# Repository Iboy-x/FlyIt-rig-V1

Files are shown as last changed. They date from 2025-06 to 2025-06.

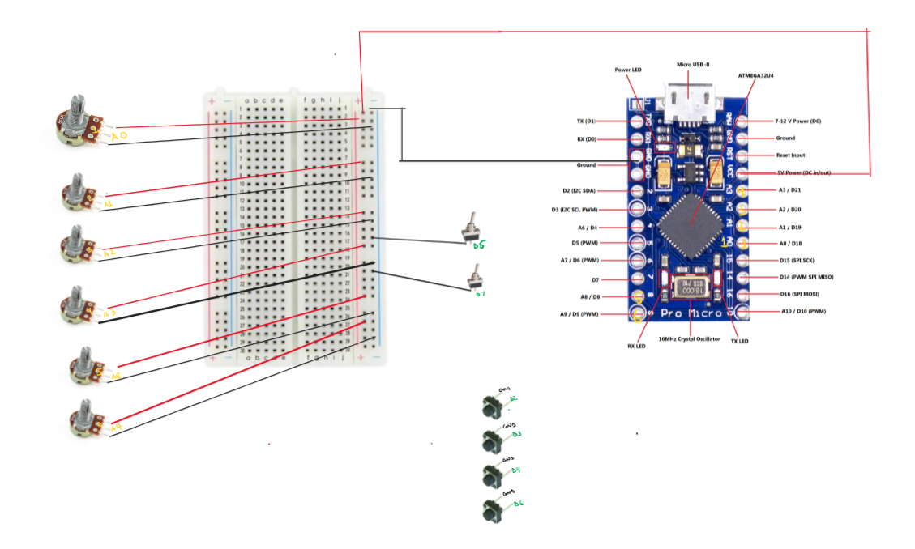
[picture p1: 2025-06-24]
Images/schematic.png

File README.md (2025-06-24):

# 🛫 FlyIt Rig V1
FlyIt Logo

**FlyIt Rig V1** is a DIY, USB-compatible flight yoke + throttle + pedal brake system made for **Microsoft Flight Simulator 2025**. The goal is to build a complete, realistic flight control rig — using affordable parts, Arduino, custom 3D prints, and pure ✨ sweat + logic ✨.

## 🎯 Project Goal

> Build a budget-friendly, USB-compatible flight controller that works with MSFS 2025 — including:
- A smooth, precise **flight yoke**
- Functional **throttle quadrant**
- Responsive **pedal brake system**
- Custom **control panel** with switches/buttons

I found lots of amazing YouTube builds — but only for individual components. My mission? **Combine them all into one fully working beast.**

---

## 🧠 Why It’s Advanced

- Heavy use of **CAD** & **3D printing** for mechanical parts
- Precision design — bearings, rods, and mounts need to be aligned just right
- **Arduino HID programming** to make it work as a real USB joystick
- Reverse engineering to get it working seamlessly with **Microsoft Flight Simulator**
- Tons of debugging, prototyping, and integration

This ain't your average DIY — it’s serious hacker engineering 😤

---

## 🛠️ Tech Stack

- 🧠 **Arduino Micro** (native USB HID support)
- 💻 Microsoft Flight Simulator 2025
- 🧰 Fusion 360 (CAD + 3D printing)
- 🛞 Bearings, steel rods, potentiometers
- 🧼 Custom control box with buttons/switches

---

## 🗂️ Build Plan

I’ll be building in stages — one module at a time:

1. **Flight Yoke** (axis + spring + centering system)
2. **Throttle Quadrant** (with friction + detents)
3. **Control Panel** (switches, buttons, and toggle controls)
4. **Brake Pedals** (paddle-style system)

Every step will be logged in `JOURNAL.md` for transparency and learning.

---

## 🔗 Inspirations

- [DIY Throttle Quadrant Guide](https://youtu.be/BRk2fzmqIq4)
- [Pedal Brake System Concept](https://youtu.be/YEzn16pNJ3I)

More design references and files will be added as I build & iterate.

---

## 🚧 Current Status

> ✅ Proposal submitted on Pitstop  
> 🚧 Hardware sourcing ongoing  
> 🔜 CAD design for yoke and controller done
> 🔜 First prototype in progress

---

## 📸 Images & Progress



Yoke Render Desing: 



Controller Render: 



Pedal Render:



### Schemtics 



---

## 🧾 License

MIT — feel free to remix and build your own FlyIt Rig! Just don’t forget to share it back with the community 💛

---
## 💸 Bill of Materials (Est. $150)

| Component | Qty | Est. Price |
|---|-----|---|
| Arduino Micro | 1 | $15 |
| 8mm x 200mm Steel Rods | 8 | $50 |
| 30x42x7 Bearings | 6 | $25 |
| LM8UU Linear Bearings 8mm*45mm| pack of 10 | $5.5 |
| V-Slot Bearings | 1pack of 12 | $9 |
| 3/8 x 7/8 Bearings | 2 | $3 |
| Potentiometers | 8 | $5 |
| Switches & Buttons | Few | ~$10 |
| 6mm Mounting Hubs | 2 | $12 |
| Wiring, base, misc parts | - | ~$15 |
|Almunimum angle rods 200mm | 2 | $20 |
| **3D Printing** | - | Covered by Hack Club (#printing-legion) |

---

### ✈️ Wheels up, dreams up.
> Made by [@AbdulMoiz](https://github.com/iboy-x) · Hack Clubber · Pilot in progress · Builder for life

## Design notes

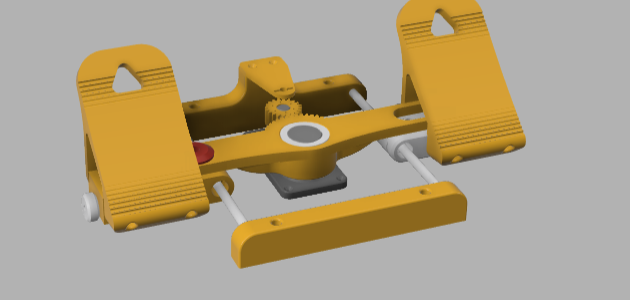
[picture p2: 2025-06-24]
Images/padel1.png

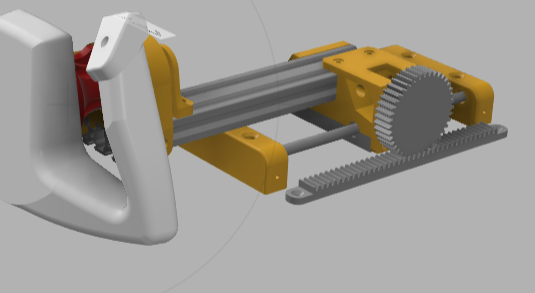
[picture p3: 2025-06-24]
Images/yoke2.png

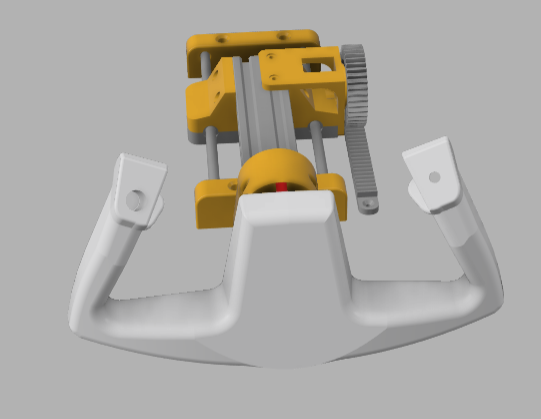
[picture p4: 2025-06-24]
Images/YOke1.png

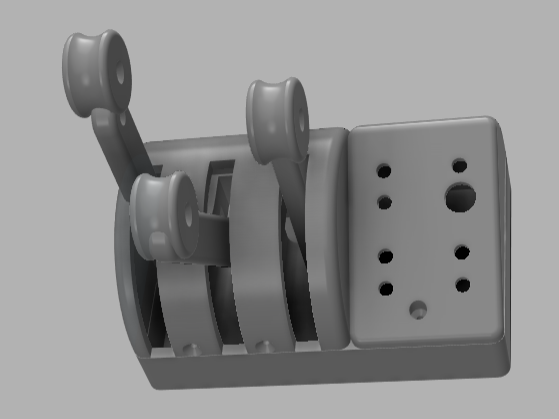
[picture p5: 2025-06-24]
Images/Controller.png

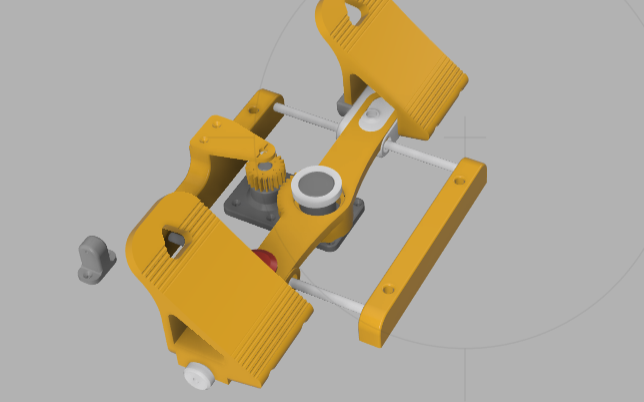
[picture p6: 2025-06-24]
Images/padel2.png

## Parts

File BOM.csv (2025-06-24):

Part Name | Quantity | Estimated Cost (USD) | Supplier | Link | Notes
Arduino Micro | 1 | 10 | AliExpress | https://www.aliexpress.com/item/1005006160273196.html | Built-in USB HID
8mm x 200mm Steel Rods | 8 | 40 | AliExpress | https://www.aliexpress.com/item/1005001380920260.html | Yoke + linear motion axis
30x42x7 Bearings | 6 | 20 | AliExpress | https://www.aliexpress.com/item/1005007420073930.html | Bearing rollers
LM8UU Linear Bearings | 6 | 5.5 | AliExpress | https://www.aliexpress.com/item/1005007009945187.html | Pack of 10
V-Slot Bearings | 12 | 9 | AliExpress | https://www.aliexpress.com/item/1005005890959821.html | Pack of 12
3/8 x 7/8 Bearings | 2 | 3 | — | — | General hardware store item
Potentiometers | 8 | 5 | AliExpress | https://www.aliexpress.com/item/32908524525.html | Axis + controls
Toggle Switches | 2–3 | 5 | AliExpress | https://www.aliexpress.com/item/1005008304283071.html | For control panel
Push Buttons | 4–5 | 5 | AliExpress | https://www.aliexpress.com/item/1005001995455752.html | Inputs for controller
Mounting Hubs (6mm) | 2 | 12 | AliExpress | https://www.aliexpress.com/item/1005002439971089.html | For pot shaft connection
Wiring + Connectors | — | 15 | Local/Other | — | Misc wiring & connector stuff
3D printing | — | — | Printing legion | —
Aluminum Angle | 1 set | 15 | AliExpress | https://www.aliexpress.com/item/1005003428294239.html | Structural rig support
Total Estimated Cost | — | 144.5 | — | — | ?? approx 150$

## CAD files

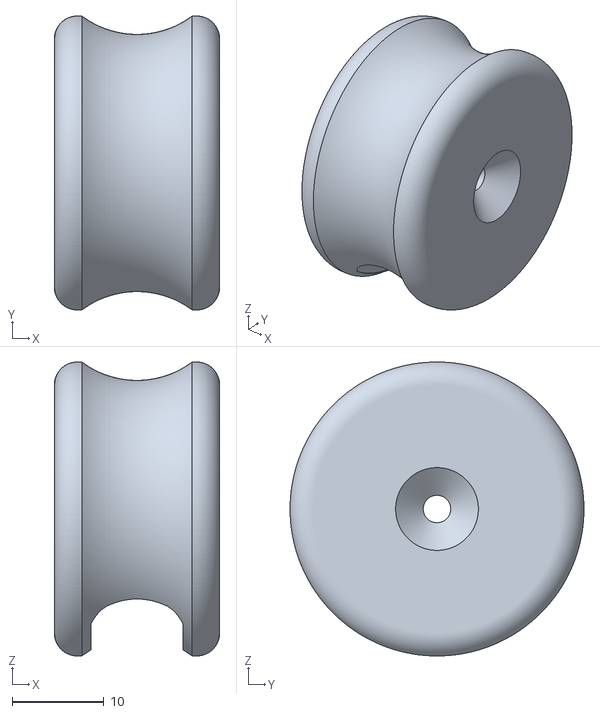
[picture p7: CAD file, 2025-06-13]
Controller/5-Knob_lever.stl
18.0 x 32.0 x 32.0

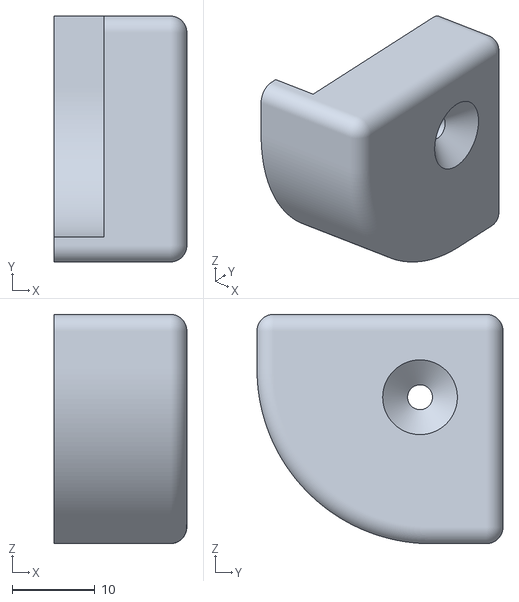
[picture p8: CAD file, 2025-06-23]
Padel/8-pedaljoiner x2.stl
16.0 x 29.7 x 27.7

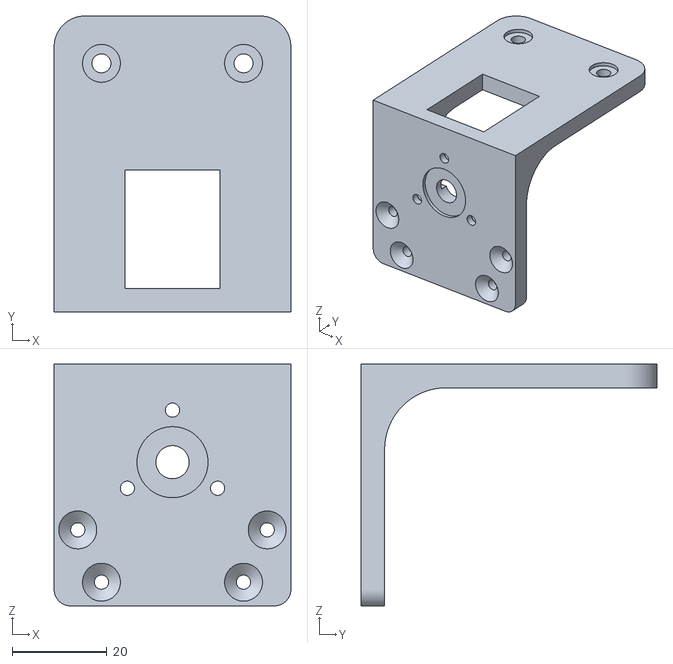
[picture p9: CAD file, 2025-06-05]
yoke/8-RotaterHolderpitch.stl
50.0 x 62.5 x 51.1

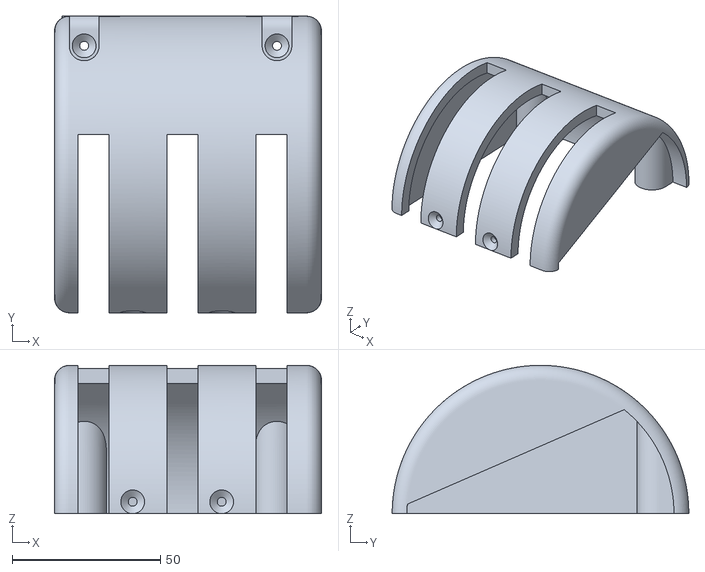
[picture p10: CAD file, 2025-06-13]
Controller/4-Top_controller.stl
90.0 x 100.0 x 50.0

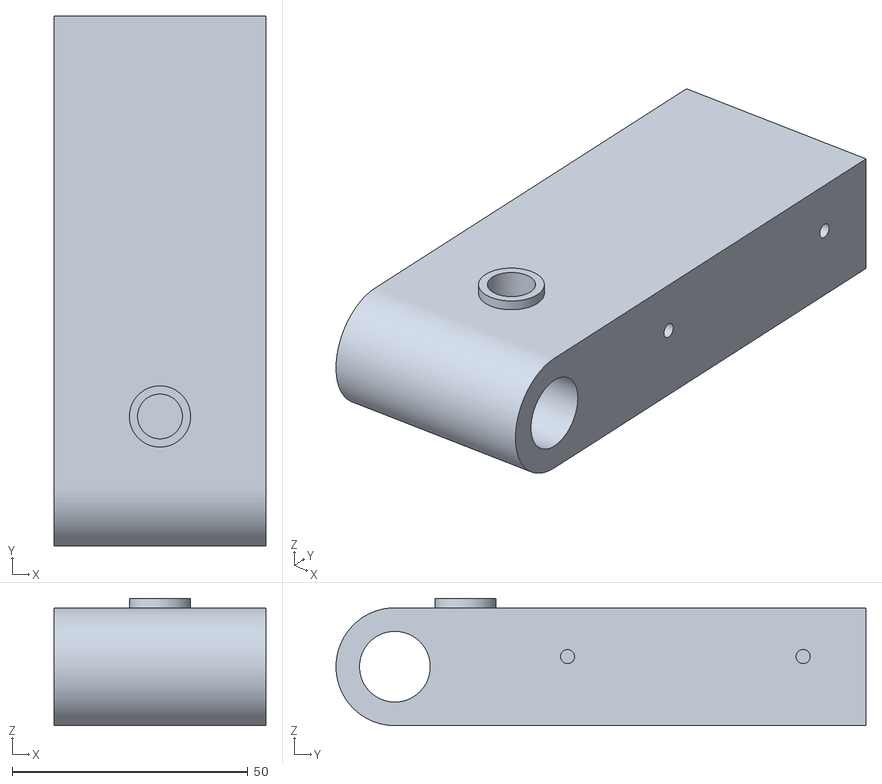
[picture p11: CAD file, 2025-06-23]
Padel/2.1 pedalholder.stl
45.0 x 112.5 x 27.0

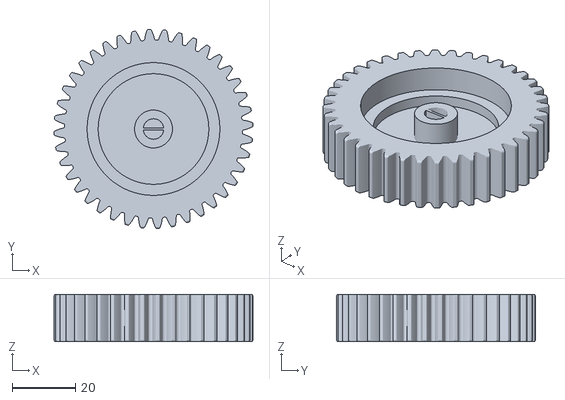
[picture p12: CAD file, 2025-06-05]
yoke/9-PotHolder.stl
63.0 x 63.0 x 15.0

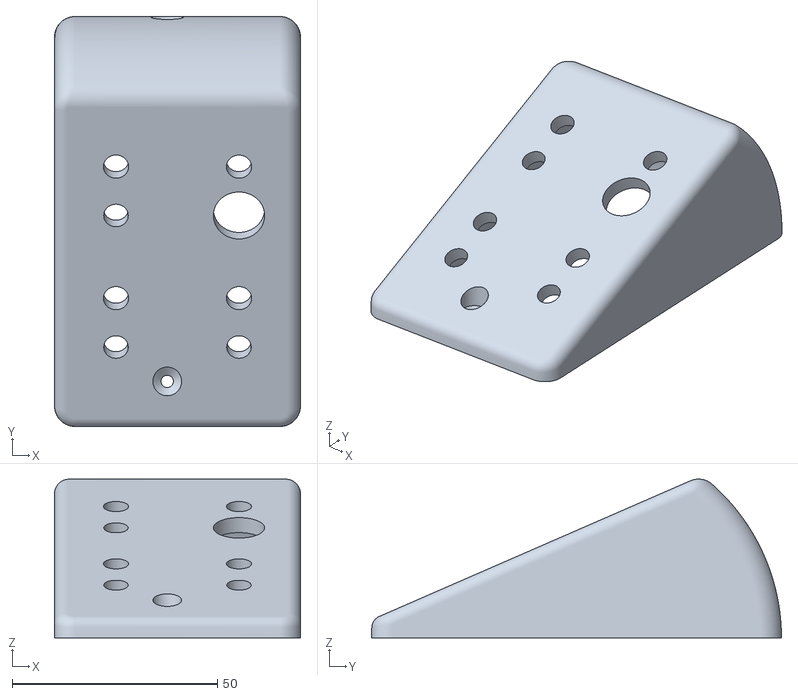
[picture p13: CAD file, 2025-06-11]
Controller/2-ButtonsCover.stl
60.0 x 100.0 x 38.7

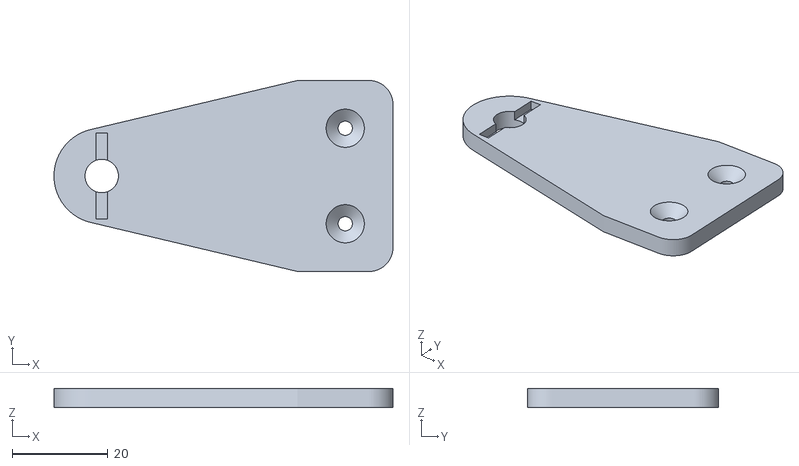
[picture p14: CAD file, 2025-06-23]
Padel/9-potentiometerHold.stl
71.0 x 40.0 x 4.00

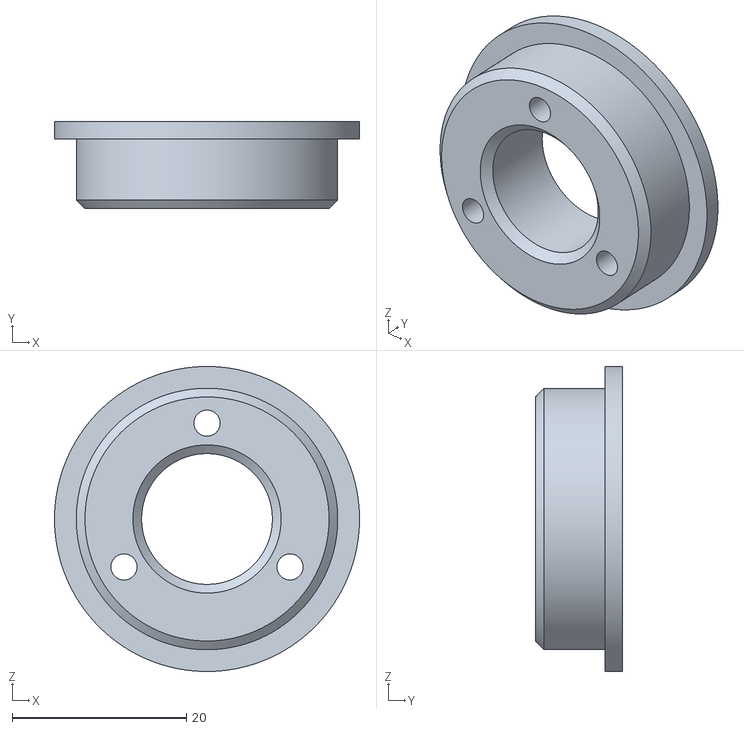
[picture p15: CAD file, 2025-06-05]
yoke/11-pinoinholder.stl
35.0 x 10.0 x 35.0

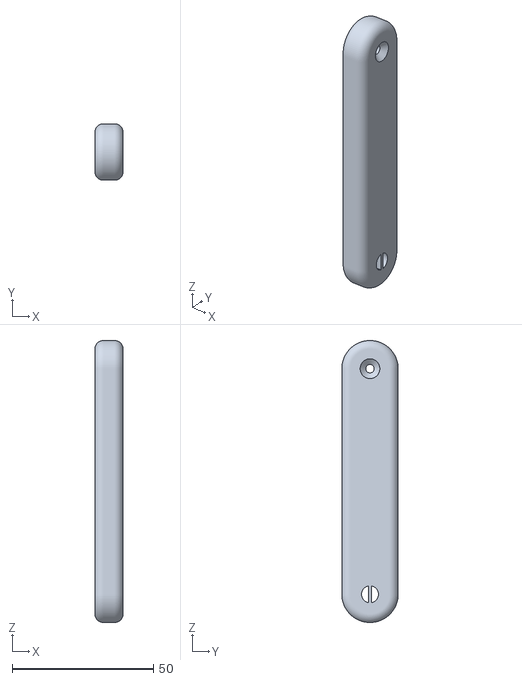
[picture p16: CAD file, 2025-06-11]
Controller/3-Leverx3.stl
10.0 x 20.0 x 100.0

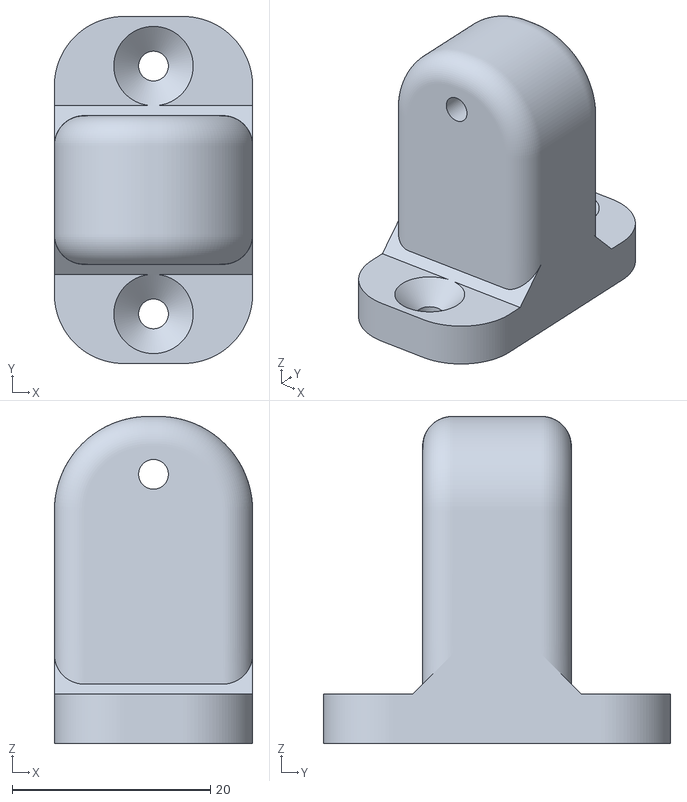
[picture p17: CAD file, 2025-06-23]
Padel/10-RubberHolder.stl
20.0 x 35.0 x 33.0

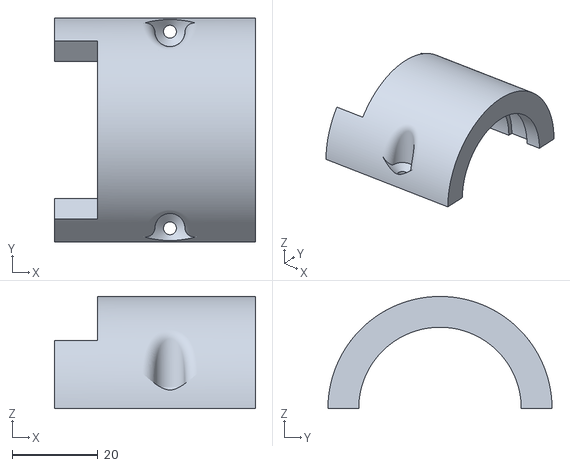
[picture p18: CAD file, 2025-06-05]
yoke/15-bearingcasingup.stl
47.0 x 52.4 x 26.2

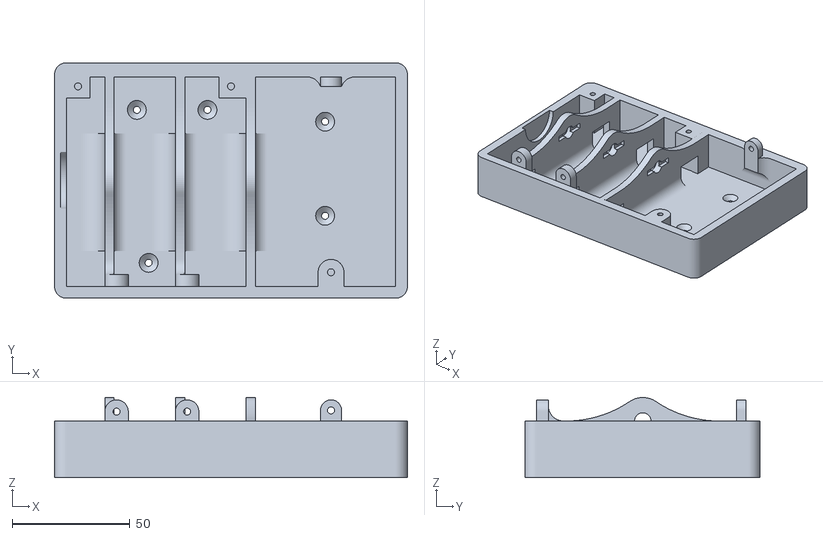
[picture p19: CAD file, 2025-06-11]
Controller/1-Base.stl
150.0 x 100.0 x 34.0

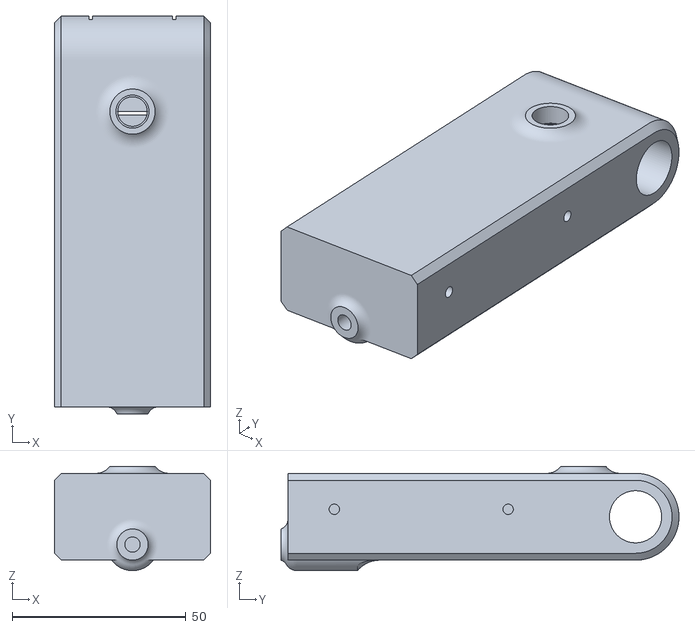
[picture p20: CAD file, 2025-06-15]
Padel/2.0 pedalholder.stl
45.0 x 114.5 x 30.0

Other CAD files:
yoke/14-Hubspacing.stl
Padel/6-Rod Holder 1.stl
yoke/12-LBHupperpart.stl
Padel/1-Padels x2.stl
Padel/3-BarPadHol.stl
Padel/4-pot,BarHolder.stl
Padel/5-Gear-holder.stl
Padel/7- Rod Holder 1.stl
yoke/1-Yoke.stl
yoke/10-PotentiometerRoller.stl
yoke/13-LBHlowerpart.stl
yoke/16-bearingcasingdown.stl
yoke/2-Yoke Shaft.stl
yoke/4-Rodends 1.stl
yoke/5-Rodends2.stl
yoke/6-RackStrip.stl
yoke/7-rotaterholder.stl

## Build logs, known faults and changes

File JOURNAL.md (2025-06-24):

# 🛠️ JOURNAL.md 

# time spent : 50 hours approx 💀💀

## 🗓️ May 20, 2025 (started)

### ✅ What I Did
- Finalized the project idea for **FlyIt Rig V1** — a DIY flight controller for MSFS 2025
- Wrote and submitted my **project proposal** on Hack Club’s Pitstop
- Planned the **project structure** (yoke → throttle → control panel → brake system)
- Estimated a **$150 BOM** and listed all hardware components needed
- Found YouTube videos as **inspiration/research** for the throttle and brake mechanics
- Wrote a full, clean `README.md` for my GitHub repo

### ⏱️ Time Spent
~3 hours

### 📚 What I Learned / Struggled With
- Learned how to break down a massive idea into modular, manageable parts
- Researched part compatibility — especially bearings, rods, and potentiometers
- Felt a little overwhelmed at first, but breaking it into phases helped a lot
- Struggled to find some exact hardware sources that accept Hack Club card — might need help or workarounds for that later

---

### 🚀 Next Up:
- Begin CAD for the **yoke mechanism**
- Start sourcing/ordering parts from vendors (or ask Hack Club for support)
- Prep second journal entry after progress on CAD or prototyping

---

## 🗓️ May 20, 2025 (Entry #2 - Yoke Design Phase)


### ✅ What I Did
- Starte working on the **Yoke mechanism CAD design**
- Took inspiration from existing YouTube builds, but began my **own design from scratch** using Fusion 360
- Figured out how the **shaft and bearings** will align inside the casing
- Identifie that a **solid mounting system** is going to be critical (and maybe tricky) for smooth movement

### ⏱️ Time Spent
~ 4 hours

### 📚 What I Learned / Struggled With
- Learned how to model support brackets and fit the 8mm steel rods properly
- Realized 3D printed parts need extra spacing/tolerances to avoid binding
- Still unsure about the **best place to mount potentiometers** for max accuracy — will need to test with physical parts

---

### 🔜 Next Up
- Finish detailed yoke model (there are still lots of things :( ) 
---

## 🗓️ May 29, 2025 (Entry #3 - Yoke Design Phase)
yeah ik its after a long time i was having exams :c




### ✅ What I Did
- Did more working on the **Yoke mechanism CAD design**
- figured how can i attach yoke to bearings and make it move. 

### ⏱️ Time Spent
~ 4.5 hours 

### 📚 What I Learned / Struggled With
- It was very difficult :( learnd legit a lot of things about mechanical parts and tried to attach them to each other.
- struggle alot with it and thats what i learned 

---

### 🔜 Next Up
- have to make a enclosure where i can fit that shaft 
- more work on Yoke mechanism left.

---

## 🗓️ June 5 2025 (Entery #4 Yoke design done :) 
It was again after a very very long time sorry i was again occupied with papers and stuff and locked in in building! 



### ✅ What I Did
- completed the Yoke mechanism finally and also update the `Yoke` folder in guthub 
- assembled all the things together in fusion.

### ⏱️ Time Spent
~15 hours it was like during the two weeks i cant update my journal in beween. 

### 📚 What I Learned / Struggled With
- I used few pre built models for the parts i can find as per my requirement.
- Assembling all the things together got me it was terrible have to change all the designs again and again to adjust.
- I am pretty good now in 3D modelling

---

### 🚀 Next Up:
- Begin CAD for the **Controller** like cessna 
- hace to make a rough sketch first.

---

## 🗓️ June 11 2025 (Entery #5 startede :) 
Finally onto the next stage :
Base of controller :



buttons top:



Leverr: 



### ✅ What I Did
- Started the Controller Mechanism CAD and made the `Controller` folder in repo
- completed almost all the parts except for 

### ⏱️ Time Spent
~ 9 hours it was like during few days. 

### 📚 What I Learned / Struggled With
- Struggle with first designing the main part hw many lever should be there how could the levers work and things
- It was smth actually difficult to make mechanism for ez for CAD lol. (I almost crash out) 
- Finally added 3 levers like cessna 

---

### 🚀 Next Up:
- have to complete controller design and also assemble them together 😭😭

---

## 🗓️ June 13 2025 (Entery #6 Controller Box DONNNE :) 
Finally Completed the controller box.

working insight: 



Assembled:





### ✅ What I Did
- Completed all the parts for Controller and assembled it !! 
- Another part of my project is completed.

### ⏱️ Time Spent
~ 5 hours  

### 📚 What I Learned / Struggled With
- It was a pretty easy thing so nothing much struggle this time just copy pasting elements twice.

---

### 🚀 Next Up:
- Move onto the `Padel` system and them coddddeeeeee it 

---

## 🗓️ June 14 2025 (Entery #7 A LOGO and design ) 
I made a logo and CAD for it :) 


### ✅ What I Did
- made the `logo` folder for it to upload png and stl of logo 
- A major thing added out of the box tho. 

### ⏱️ Time Spent
~ 15 mins for cad and 45 mins for designing it :\ 

### 🚀 Next Up:
- Move onto the `Padel` system !!!!

---

## 🗓️ June 15 2025 (Entery #8 Finally padels half way done !  ) 
finally started working on padels and stuff took inspo for mechanism from this: https://www.youtube.com/watch?v=vinw3yeDGUQ



### ✅ What I Did
- made the CAD for padels, Padels holder and potentiometer holder 
- made the folder for `pedals` and added files that i worked on today and yesterday.
- ALso I used few previous models like edited them a bit.

### ⏱️ Time Spent
~ 5.5 hour approx 

### 🚀 Next Up:
- complete pedal system and move onto code (I cant w8 to comlete it ) 

---

> I saw a lil bit lacking in journal 😭 like how the potentiometers and where which part will be used that i will be buysing thi swill ensure that i am buying right quantity and thing so will be updating it soon by night

---

## Here which material will be used where is mentioned 😤!

### Yoke: 
- 2x 30x42x7mm bearings for yoke holder
- mounting hubs 6mm  for potentiometer holder 
- 2x potentiometer for recognising movements
- 2x 8mm x 200mm Steel Rod for yoke movement
- 2x puch buttons for yoke handle. 
- 2x Almunium angles rod (forgot to add these initially)
- Linear bearing 8mm*45mm (realized i have selected smaller one) 

 ### Controller:
  - 3x potentiometer for each lever
  - few toggle buttons
  - few leds
  - few push buttons 

---

## 🗓️ June 23 2025 (Entery #9 PEDALSSSS DONEEE !  ) 
finally i was able to complete the pedals !!!!!!! and also the code is almost complete btw i was gone for a long time have some problem but i am back. 



### ✅ What I Did
- completed rest of the desings and thier cad 
- assembled all the designs and finished pedals mechanism. 
- again used the older desings like potentiometer mechanism. 
- code almost done but i will made a separate entry for it :) 

### ⏱️ Time Spent
~ 6.3 hours approx

### 🚀 Next Up:
- uloading the code after verifying few things. then schematics drawing. 

---
## 🗓️ June 23 2025 (Entery #10 CODE completed  ) 
I wrote the code verify it by AI to make sure it will work with potentiometer and buttons and for arduino micro. 

### 🧠 How it works 
- so basically potentiometer movement is devided and with the moment of potentiometer pitch and roll changes which changes the axis of the plane and allow it to move
- also i found library for joy stick on github i have added its link at the top of the code so that it can be easily installed. 
- also i mapped buttons to do the on off tasks that can be mapped in the game. 

### ✅ What I Did
- completed the code
- use the codes of others to understand pretty much logic.

### ⏱️ Time Spent
~ 2 hours approx 

### 🚀 Next Up:
- Schematics, final BOM and then SUBMISSION 

---

## Schematics worked

## 🧰 Wiring Table – Arduino Micro Pinout for FlyIt Rig V1

### 🎮 Analog Inputs (Potentiometers)

| Function | Arduino Pin | Component | Notes |
|---|---|---|---|
| Yoke Pitch | A0 | Potentiometer  | Forward/Back |
| Yoke Roll | A1 | Potentiometer  | Left/Right |
| Throttle | A2 | Potentiometer  | Engine power |
| Extra Axis 1 | A3 | Potentiometer  | Flaps, Mixture, etc. |
| Yaw / Rudder Pedals | A8 | Potentiometer  | Twist handle or pedal input |
| Extra Axis 2 / Brakes  | A9 | Potentiometer  | Could be brake pedal or trim |

### 🕹️ Digital Inputs (Buttons & Switches)

| Button # | Arduino Pin | Type | Suggested Use |
|---|---|---|---|
| 0 | 2 | Pushbutton | Landing Gear |
| 1 | 3 | Pushbutton | Autopilot ON/OFF |
| 2 | 4 | Pushbutton | Flaps Down |
| 3 | 5 | Toggle Switch  | Magnetos or Lights |
| 4 | 6 | Pushbutton | Trim Reset or Spoilers |
| 5 | 7 | Toggle Switch  | Battery Master or Avionics|

### ⚡ Power Lines

| Power Line | Connects To |
|---|---|
| 5V | One side of all potentiometers |
| GND | Other side of potentiometers and all buttons|

--- 

## 🗓️ June 25 2025 (Entery #11 DOne for submission ) 
ffinally everything is assembled with the schematics and BOM. 



### ✅ What I Did
- Completed everything now onto submission
- made schematics for the switch and buttons and potentiometer
- verify i have all the things available. 

### ⏱️ Time Spent
~ 1.5 hours approx

### 🚀 Next Up:
- submission then building irl.

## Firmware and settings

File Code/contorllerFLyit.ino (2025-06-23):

// Requires Arduino Joystick Library https://github.com/MHeironimus/ArduinoJoystickLibrary
#include <Joystick.h>
Joystick_ Joystick;
 
int JoystickX;
int JoystickY;
int JoystickZ;
int Throttle;
int Rudder;
int Aux1;
int Aux2;
int currentButtonState0;
int lastButtonState0;
int currentButtonState1;
int lastButtonState1;
int currentButtonState2;
int lastButtonState2;
int currentButtonState3;
int lastButtonState3;
int currentButtonState4;
int lastButtonState4;
int currentButtonState5;
int lastButtonState5;
int currentButtonState6;
int lastButtonState6;

void setup() {
  Serial.begin(9600);
  pinMode(2, INPUT_PULLUP);
  pinMode(3, INPUT_PULLUP);
  pinMode(4, INPUT_PULLUP);
  pinMode(5, INPUT_PULLUP);
  pinMode(6, INPUT_PULLUP);
  pinMode(7, INPUT_PULLUP);
// Initialize Joystick Library
  Joystick.begin();
  Joystick.setXAxisRange(0, 965); 
  Joystick.setYAxisRange(192, 522);
  Joystick.setZAxisRange(143, 735);
  Joystick.setRxAxisRange(158, 456);
  Joystick.setRyAxisRange(158, 456);
  Joystick.setThrottleRange(154, 448);
}

void loop() {

// Read Joystick
  JoystickX = analogRead(A0);
  JoystickY = analogRead(A1);
  JoystickZ=analogRead(A8);
  Throttle=analogRead(A2);
  Aux1=analogRead(A9);
  Aux2=analogRead(A3);
  Serial.print(JoystickX);
  Serial.print("   ");
  Serial.print(JoystickY);
  Serial.print("   ");
  Serial.println(JoystickZ);


// Read Switches
int currentButtonState0 = !digitalRead(2); // Button 0
  if (currentButtonState0 != lastButtonState0)
  {
  Joystick.setButton(0, currentButtonState0);
  lastButtonState0 = currentButtonState0;
  }

int currentButtonState1 = !digitalRead(3); // Button 1
  if (currentButtonState1 != lastButtonState1)
  {
  Joystick.setButton(1, currentButtonState1);
  lastButtonState1 = currentButtonState1;
  }
  
int currentButtonState2 = !digitalRead(4); // Button 2
  if (currentButtonState2 != lastButtonState2)
  {
  Joystick.setButton(2, currentButtonState2);
  lastButtonState2 = currentButtonState2;
  }

int currentButtonState3 = !digitalRead(5); // Button 3
  if (currentButtonState3 != lastButtonState3)
  {
  Joystick.setButton(3, currentButtonState3);
  lastButtonState3 = currentButtonState3;
  }
  
int currentButtonState4 = !digitalRead(6); // Button 4
  if (currentButtonState4 != lastButtonState4)
  {
  Joystick.setButton(4, currentButtonState4);
  lastButtonState4 = currentButtonState4;
  } 

int currentButtonState5 = !digitalRead(7); // Button 5
  if (currentButtonState5 != lastButtonState5)
  {
  Joystick.setButton(5, currentButtonState5);
  lastButtonState5 = currentButtonState5;
  } 
  
   
// Output Controls
  Joystick.setXAxis(JoystickX);
  Joystick.setYAxis(JoystickY);
  Joystick.setZAxis(JoystickZ);
  Joystick.setThrottle(Throttle);
  Joystick.setRxAxis(Aux1);
  Joystick.setRyAxis(Aux2);
  Joystick.sendState();

} 

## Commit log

2025-05-29 Add files via upload
    updated yoke parts
    [1-Yoke.stl, 2-Yoke Shaft.stl, 3-Yoke Pot holder.stl]
2025-06-05 Yipppeee Yoke done
    [10-PotentiometerRoller.stl, 11-pinoinholder.stl, 12-LBHupperpart.stl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]
2025-06-11 uploaded the controller desing
    [1-Base.stl, 2-ButtonsCover.stl, 3-Leverx3.stl]
2025-06-13 Controller doneeeeee
    [4-Top_controller.stl, 5-Knob_lever.stl]
2025-06-15 Add files via upload
    Padels Half way done :)
    [1-Padels x2.stl, 2-Padel Holder x2.stl, 3-BarPadHol.stl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]
2025-06-24 Add files via upload
    DONE
    [BOM.csv]
